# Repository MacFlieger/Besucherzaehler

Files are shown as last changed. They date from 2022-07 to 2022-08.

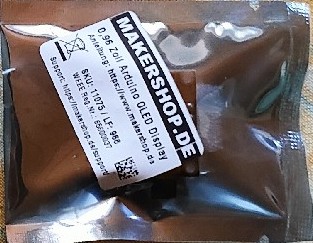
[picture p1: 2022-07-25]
Komponenten/OLED Display SSD1306.jpg

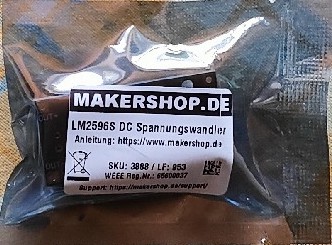
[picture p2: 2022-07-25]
Komponenten/LM2597S.jpg

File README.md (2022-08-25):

# Besucherzaehler

Besucherzähler für die Bibi Wulfen

## Kurzbeschreibung

Mittels einer Lichtschranke sollen Besucherzahlen mit einem ESP8266 Mikrocontroller gemessen und angezeigt werden.

## Komponenten

- Wemos D1 Mini ESP8266 Mikrokontroller
- LM2596S DC Spannungswandler
- 0,96" OLED Display SSD1306 blau 128x64 I2C
- 12V Lichtschranke

## Schaltplan

Im Ordner "Schaltung" sind die KiCad-Dateien und der aktuelle Schaltplan als PDF gespeichert.

## Software

Im Ordner "Zaehler" ist die aktuelle Software gespeichert. Hauptprogramm ist "Zaehler.ino"

## Aufteilung des Bildschirmes

Gesamtgröße 128x64 Pixel

- Zeile 0-15 (16px hoch): Besucheranzahl
	- Spalte 0-11: Markierung für einen halben Besuchers (nur Eintritt)
	- Spalte 12-127: Anzeige der Besucheranzahl
- Zeile 45-52 (8px hoch): Anzahl der geblockten Ereignisse
- Zeile 53-55 (3px hoch): Trennlinie 
- Zeile 56-63 (8px hoch): Statusanzeige
	- Spalte 0-7 (8px breit): Zustand der Lichtschranke
	- Spalte 92-127 (6char=36Pixel breit): Anzeige der Spannung

## Nützliches

Tabelle der Sonderzeichen bei Wikipedia  
[Codepage 437](https://de.wikipedia.org/wiki/Codepage_437)

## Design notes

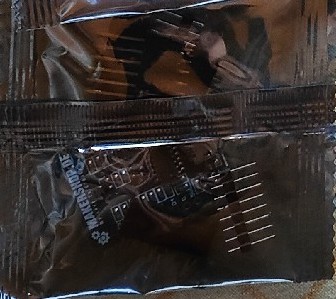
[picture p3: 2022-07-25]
Komponenten/Wemos D1 Mini ESP8266.jpg

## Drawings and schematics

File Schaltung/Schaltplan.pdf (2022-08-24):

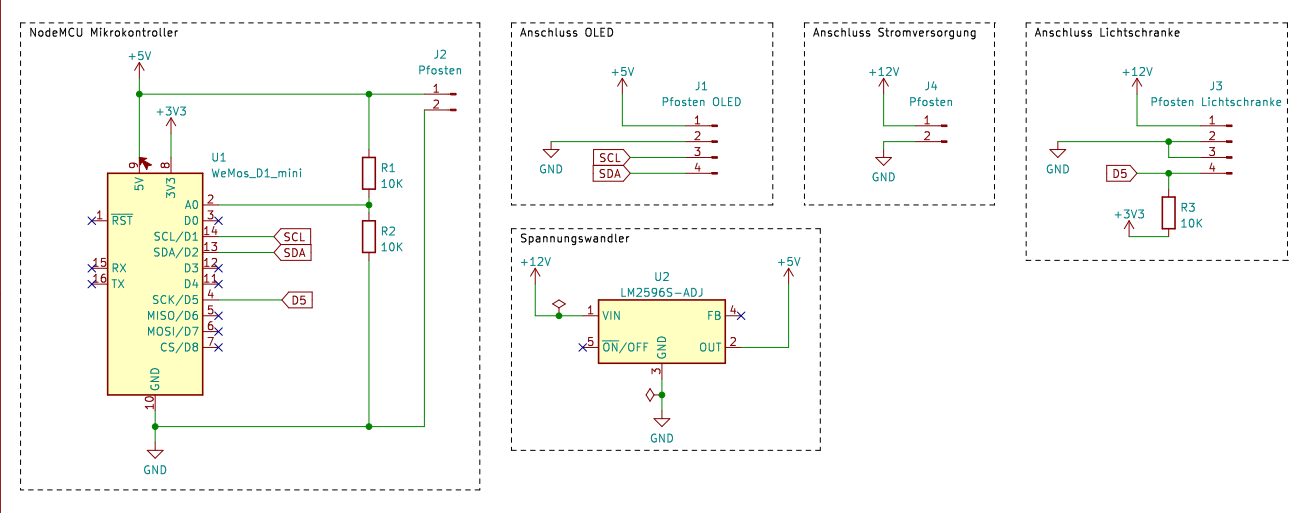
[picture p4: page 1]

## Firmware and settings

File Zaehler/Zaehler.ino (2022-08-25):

/**************************************************************************
Besucherzähler für die Bibi Wulfen

Version 0.7
(c) 2022 Jörg Skapski, Markus Soick
**************************************************************************/

// Bibliotheken
#include <SPI.h>
#include <Wire.h>
#include <Adafruit_GFX.h>
#include <Adafruit_SSD1306.h>

// Version
#define VERSION "(c) 2022, v0.7"

// Konstanten
#define PIN_U A0        // Eingangs-Pin zur Spannungsmessung
#define PIN_LS D5       // Eingangs-Pin für die Lichtschranke (D5=GPIO14)
#define ZEITMINIMUM 200 // Minimalzeit in ms zwischen zwei Zählungen

// OLED-Display
#define SCREEN_WIDTH 128 // OLED display width, in pixels
#define SCREEN_HEIGHT 64 // OLED display height, in pixels
#define OLED_RESET    -1 // Reset pin # (or -1 if sharing Arduino reset pin)
#define SCREEN_ADDRESS 0x3C
#define WEISS SSD1306_WHITE
Adafruit_SSD1306 display(SCREEN_WIDTH, SCREEN_HEIGHT, &Wire, OLED_RESET);

// Globale Variablen
unsigned long timerZeit=0;      // Zeit der letzten Timerausführung
unsigned long lsZeit=0;         // Zeit der letzten LS-Unterbrechung
unsigned long zaehler=0;        // Anzahl der Besucher
unsigned long geblockt=0;       // Anzahl der geblockten Ereignisse
boolean lsAenderung=false;      // Flag für die Aktualisierung des LS-Zustandes
boolean zaehlerAenderung=false; // Flag für die Aktualisierung des Zählers
boolean durchgang=false;        // Flag zum Halbieren der erfassten Durchgänge (Rein und Raus sind ein Besucher)

void ICACHE_RAM_ATTR lsUnterbrechung() {
  // die Lichtschranke hat den Zustand geändert
  if (digitalRead(PIN_LS)) {
    // die LS ist frei
    lsAenderung=true;
  }
  else {
    // die LS ist unterbrochen
    lsAenderung=true;
    unsigned long zeit=millis();
    // Prellen der LS unterdrücken
    if (zeit<lsZeit || zeit-lsZeit>1) {
      if (zeit-lsZeit<ZEITMINIMUM) {
        // Zu kurze Zeit zwischen zwei Ereignissen, wird nicht gewertet
        geblockt++;
        zaehlerAenderung=true;
        lsZeit=zeit;
      }
      else {
        // Ereignis muss gezählt werden
        durchgang=!durchgang;
        if (!durchgang)
          zaehler++;
        zaehlerAenderung=true;
        lsZeit=zeit;
      }
    }
  }
}

void setup() {
  // Pins initialisieren
  pinMode(PIN_LS,INPUT);

  // OLED initialisieren
  display.begin(SSD1306_SWITCHCAPVCC, SCREEN_ADDRESS);
  display.cp437(true);         // Use full 256 char 'Code Page 437' font
  display.clearDisplay();
  display.display();

  // Startbildschirm
  startbild();

  // Maske mit Inhalten ausgeben
  ausgabeMaske(true);

  // Interrupt für die Lichtschranke aktivieren
  attachInterrupt(digitalPinToInterrupt(PIN_LS), lsUnterbrechung, CHANGE);

}

void loop() {
  // jede Sekunde die Anzeige der Spannung aktualisieren
  unsigned long zeit=millis();
  if (zeit<timerZeit || zeit-timerZeit>1000) {
    timerZeit=zeit;
    ausgabeSpannung();
  }
  // evtl. Aktualisierung des Zustandes der Lichtschranke
  if (lsAenderung) {
    ausgabeLS();
  }
  // evtl. Aktualisierung des Zählers
  if (zaehlerAenderung) {
    ausgabeZaehler();
  }
}

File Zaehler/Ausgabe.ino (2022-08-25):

/**************************************************************************
Unterprogramme für die Ausgabe auf dem OLED-Display

startbild: Anzeige des Startbildes
ausgabeMaske: Anzeige der Maske
ausgabeZaehler: Anzeige der aktuellen Besucherzahl
ausgabeLS: Anzeige des Zustandes der Lichtschranke
ausgabeSpannung: Anzeige der Spannung

**************************************************************************/

void startbild() {
  // Anzeige des Startbildschirmes
  display.setTextColor(SSD1306_WHITE);
  display.setTextSize(2);
  display.setCursor(12,0);
  display.print(F("Besucher-"));
  display.setCursor(24,16);
  display.print(F("z\x84hler"));
  display.setTextSize(1);
  display.setCursor(0,40);
  display.println(F(VERSION));
  display.println(F("J\x94rg Skapski"));
  display.println(F("Markus Soick"));
  display.display();

  delay(5000);
  display.clearDisplay();
  display.display();
}

void ausgabeMaske(boolean alles) {
  // Anzeige der Maske
  display.drawLine(0,54,127,54,WEISS);
  // Anzeige der Inhalte
  if (alles) {
    ausgabeZaehler();  
    ausgabeLS();
    ausgabeSpannung();
  }
  display.display();
}

void ausgabeZaehler() {
  zaehlerAenderung=false;
  display.fillRect(0,0,128,16,SSD1306_BLACK);
  display.setTextColor(SSD1306_WHITE);
  display.setTextSize(2);
  if (durchgang)
    display.fillCircle(5,7,3,SSD1306_WHITE);
  display.setCursor(12,0);
  display.print(zaehler);
  display.fillRect(0,45,128,8,SSD1306_BLACK);
  display.setTextSize(1);
  display.setCursor(0,45);
  display.print(F("geblockt: "));
  display.print(geblockt);
  display.display();
}

void ausgabeLS() {
  // Anzeige des Zustandes der Lichtschranke
  boolean zustand=digitalRead(PIN_LS);
  lsAenderung=false;
  display.fillRect(0,56,8,8,SSD1306_BLACK);
  if (zustand)
    display.drawCircle(4,60,3,SSD1306_WHITE);
  else
    display.fillCircle(4,60,3,SSD1306_WHITE);
  display.display();
}

void ausgabeSpannung() {
  // Anzeige der Spannung
  display.fillRect(92,56,36,8,SSD1306_BLACK);
  float u=(analogRead(PIN_U)/1023.)*3.3*1.91;
  display.setTextColor(SSD1306_WHITE);
  display.setTextSize(1);
  display.setCursor(92,56);
  display.print(u);
  display.print(F(" V"));
  display.display();
}

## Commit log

2022-07-25 Schaltplan hinzugefügt
    [Besucherzaehler.kicad_pcb, Besucherzaehler.kicad_sch]
2022-07-30 Schaltplan um Spannungsmessung erweitert
    [Besucherzaehler.kicad_sch]
2022-07-30 Anzeige der Lichtschranke ergänzt
2022-08-24 Eingang der Lichtschranke auf D5 geändert
    [Besucherzaehler.kicad_sch]
2022-08-24 Zählen der Unterbrechungen per Interrupt
2022-08-25 Nur jeder 2. Durchgang durch die Lichtschranke wird gezählt.
